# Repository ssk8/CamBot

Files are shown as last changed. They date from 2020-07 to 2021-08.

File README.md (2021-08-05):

# Auto camera tracker
in action: https://youtu.be/omu7OnxMOV8

This is an expansion on my PoC auto-tracking camera system. The first one worked but had some major shortcomings which I'm trying to address.

Steps in setup-pi are needed to get the RF24 working on the Raspberry Pi. I'm not sure if it will run as a shell script

The mount I designed to attach the HQ camera and the Pi can be found at https://www.thingiverse.com/stinkyskate/designs

The transmiter is a Feather M0 express with protowing for radio/gps attachemnt

The base station is a Pi 3A+ with HQcam and lens, proto hat with buttons, sdd1306 oled, trinket M0 (for stepper driver), radio

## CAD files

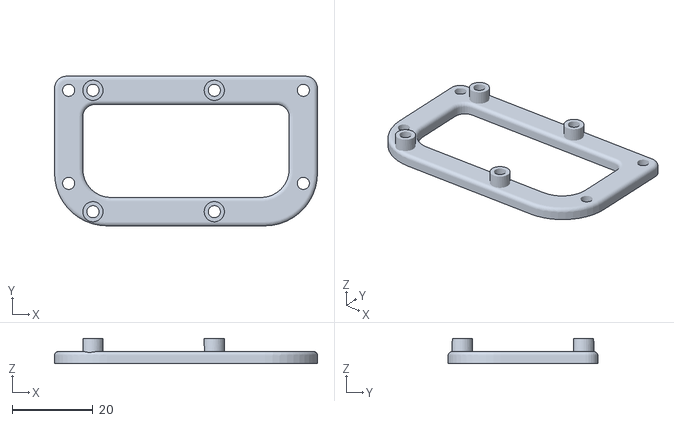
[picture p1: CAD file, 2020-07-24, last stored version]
HQZ.stl
65.0 x 37.0 x 6.25

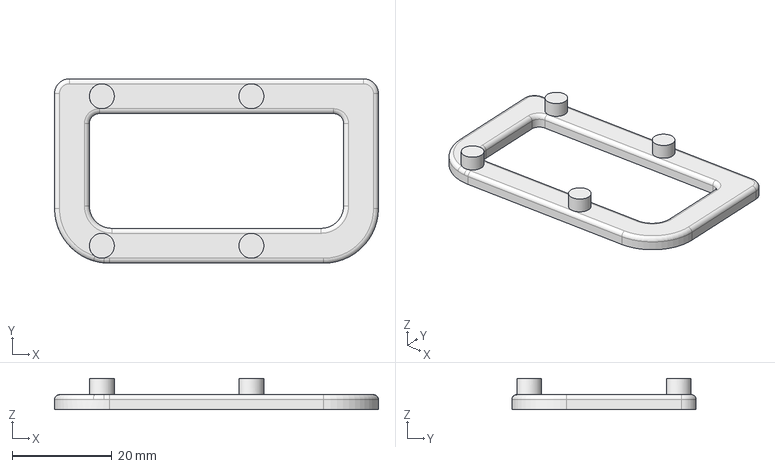
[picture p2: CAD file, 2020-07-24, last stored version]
HQZR3.FCStd
65.0 x 37.0 x 6.25 mm

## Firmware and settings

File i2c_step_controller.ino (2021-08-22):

#include <AccelStepper.h>
#include <Adafruit_DotStar.h>
#include <Wire.h>

#define nperRev 240000 
#define SLAVE_ADDRESS 0x08
#define STEPENABLEPIN 1
#define DIRPIN 3
#define STEPPIN 4
#define DATAPIN    7
#define CLOCKPIN   8 
#define DISABLE 2147483647
#define ENABLE 2147483646

AccelStepper stepper(AccelStepper::DRIVER, STEPPIN, DIRPIN);
Adafruit_DotStar strip(1, DATAPIN, CLOCKPIN, DOTSTAR_BRG);

uint32_t red = strip.Color(0, 55, 0);
uint32_t green = strip.Color(55, 0, 0);
uint32_t blue = strip.Color(0, 0, 55);


byte raw_data[3];
long rec_data = DISABLE;
long last_data;
long next_pos;
bool enabled;

void setup()
{ 
  //Serial.begin(115200);
  Wire.begin(SLAVE_ADDRESS);
  Wire.onReceive(receiveData); 
  stepper.setEnablePin(STEPENABLEPIN);
  stepper.setPinsInverted(false, false, true);
  stepper.disableOutputs ();
  enabled = false;
  stepper.setMaxSpeed(nperRev);
  stepper.setAcceleration(nperRev/20);
  stepper.setCurrentPosition(0);
  stepper.setAcceleration(2000);
  strip.begin();
  strip.setBrightness(80);
  strip.setPixelColor(0, green);
  strip.show(); 
  
}

void loop()
{
  if (last_data != rec_data) {
    if (rec_data == DISABLE) {
      stepper.disableOutputs();
      strip.setPixelColor(0, green);
      enabled = false;
    }
    else if (rec_data == ENABLE) {
      stepper.enableOutputs();
      strip.setPixelColor(0, red);
      enabled = true;
    }
    else
    { 
        next_pos = rec_data;
        if (enabled) {

          if (abs(stepper.currentPosition()-next_pos)>abs(stepper.currentPosition()-next_pos+nperRev)) next_pos-=nperRev;
          else if (abs(stepper.currentPosition()-next_pos)>abs(stepper.currentPosition()-next_pos-nperRev)) next_pos+=nperRev;
         
//          long dist = abs(stepper.currentPosition()-next_pos);
//          if (dist > 2000) stepper.setAcceleration(10000);
//          else if (dist < 200) stepper.setAcceleration(200);
//          else stepper.setAcceleration(dist*5-800);
          
          stepper.moveTo(next_pos);
      }
        else {
          stepper.setCurrentPosition(next_pos);
      }
    }
    last_data = rec_data;
  }

  
  if (enabled){
    if (stepper.isRunning()){
      strip.setPixelColor(0, blue);
    }
    else{
      strip.setPixelColor(0, red);
   }
  }

//  Serial.print("Current: ");
//  Serial.print(stepper.currentPosition());
//  Serial.print("  Target: ");
//  Serial.println(stepper.targetPosition());
  strip.show(); 
  stepper.run();
}


void receiveData(int bytecount)
{
  for (int i = 0; i < bytecount; i++) {
    raw_data[i] = Wire.read();
  }
  rec_data = 0;
  rec_data += raw_data[2] << 24;
  rec_data += raw_data[3] << 16;
  rec_data += raw_data[4] << 8;
  rec_data += raw_data[5];
}

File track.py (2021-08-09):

#!/usr/bin/python3

from time import sleep, time
from datetime import datetime, timedelta
import os, csv
from pathlib import Path
from RF24 import RF24
import struct
import picamera
import RPi.GPIO as GPIO
from orientation import distance, bearing
from subtitle import finish_subs
from stepper import send_step, step_enable
from oled import oled_print


n_per_rev = 240000

radio = RF24(17, 1)
irq_gpio_pin = 27
pipes = [0xF0F0F0F0E1, 0xF0F0F0F0D2]
struct_format = 'ffIIhhi????'
current_rx = bytearray()


class GPS_data():
    def __init__(self, latitude=0, longitude=0, gps_time="0000000", gps_date="010120", speed=0, course=0, altitude=0, button1=0, button2=0, button3=0, button4=0):
        self.latitude = latitude
        self.longitude = longitude
        self.time = datetime.strptime(f'{str(gps_date).zfill(6)[0:4]}20{str(gps_date)[-2:]}{str(gps_time).zfill(8)[:-2]}+00:00', '%d%m%Y%H%M%S%z')
        self.speed = speed
        self.course = course
        self.altitude = altitude
        self.button1 = button1


def radio_rx(channel=0):
    global current_rx
    if radio.available():
        while radio.available():
            len = radio.getDynamicPayloadSize()
            current_rx = radio.read(len)


def start_radio():
    radio.begin()
    radio.enableDynamicPayloads()
    radio.setRetries(5, 15)
#   radio.printDetails()
    GPIO.setmode(GPIO.BCM)
    GPIO.setup(irq_gpio_pin, GPIO.IN, pull_up_down=GPIO.PUD_UP)
    GPIO.add_event_detect(irq_gpio_pin, GPIO.FALLING, callback=radio_rx)
#   radio.openWritingPipe(pipes[1])
    radio.openReadingPipe(1, pipes[0])
    radio.startListening()


start_radio()


def set_camera(camera):
    camera.resolution = (1920, 1080)
    camera.framerate = 25
    camera.video_stabilization = True
    camera.annotate_foreground = picamera.Color('black')
    camera.annotate_text_size = 18
    camera.annotate_background = picamera.Color('white')


def unpack_data(struct_data):
    return struct.unpack(struct_format, struct_data)


def get_filename(data):
    path = Path("/")
    if '/mnt/usb0/Videos' in [str(x) for x in (path / 'mnt' / 'usb0').iterdir() if x.is_dir()]:
        path = path / 'mnt' / 'usb0' / 'Videos' 
    else:
        path = path / 'home' / 'pi' / 'Videos' 
    print(f'this is the path {path}')
    return f'{path}/{(data.time + timedelta(hours=-5)).strftime("%y%m%d%H%M%S")}'


def get_step_possition(base_gps, current_gps):
    pos = int(bearing(base_gps, current_gps)/360*n_per_rev)
    return pos


def move_camera(base_gps, current_gps):
    print(f"bearing: {int(bearing(base_gps, current_gps))}  distance: {distance(base_gps, current_gps)}")
    if distance(base_gps, current_gps) > 25:
        print('moving')
        send_step(get_step_possition(base_gps, current_gps))
    else:
        print("too close")


def annotate(cam, base, cur, filename):
    global v_data
    current_time = f'{(cur.time + timedelta(hours=-5)).strftime("%y/%m/%d %H:%M:%S")}'
#   cam.annotate_text = f'{current_time}\nspeed: {str(cur.speed).zfill(2)} mph\nalt: {(cur.altitude*0.0328084):.0f} ft'
    current_subtitle = f'{v_data[1]}\nSTART{time() - v_data[0]}\n{current_time} speed: {str(cur.speed).zfill(2)} mph  alt: {(cur.altitude*0.0328084):.0f} ft\n\n'
    with open(f'{filename}.srt', 'a') as subtitles:
        subtitles.write(current_subtitle)
    v_data[1] += 1


def get_target_coords_from_file() -> GPS_data:
    targets_coords_path = Path('/home/pi/target_coords.csv')
    places = dict()
    with open(targets_coords_path, newline='') as f:
        reader = csv.reader(f)
        for row in reader:
            place, lat, lon = row
            places[place] = (float(lat), float(lon))
    place = places[list(places.keys())[-1]]
    print(place)
    return GPS_data(latitude=place[0], longitude=place[1]) 


def track(button, camera):
    set_camera(camera)
    last_rx = bytearray()
    last_button1 = False
    base_gps_data = None
    current_gps_data = None
    pos_lock = False
    oled_print('start tracking')

    while True:
        if current_rx != last_rx:
            last_rx = current_rx
            current_gps_data = GPS_data(*unpack_data(current_rx))
            if not base_gps_data:
                base_gps_data = current_gps_data

            if pos_lock and current_gps_data.button1 and not last_button1:
                global v_data
                v_data = [time(), 1]
                last_button1 = current_gps_data.button1
                filename = get_filename(current_gps_data)
                camera.start_recording(f"{filename}.h264")
                print('recording')
                oled_print('recording')
            elif not current_gps_data.button1 and last_button1:
                camera.stop_recording()
                last_button1 = current_gps_data.button1
                finish_subs(filename)
                print('stopped recording')
                oled_print('stopped recording')
            #    os.system(f'ffmpeg -i {filename}.h264 -i {filename}.srt -vcodec copy -c:s mov_text {filename}.mp4')
            #    print("wrote mp4")
            #    os.system(f'rm {filename}.h264')
            if camera.recording:
                move_camera(base_gps_data, current_gps_data)
                annotate(camera, base_gps_data, current_gps_data, filename)
                
        if button.either:
            if button.both:
                break
            if button.A:
                if pos_lock:
                    print("possition lost")
                    oled_print("possition lost")
                    step_enable(False)
                    pos_lock = False
                else:
                    distant_place = get_target_coords_from_file()
                    if current_gps_data:
                        oled_print("lock possition")
                        #print(f"lock possition for {current_gps_data.latitude, current_gps_data.longitude}")
                        send_step(get_step_possition(base_gps_data, distant_place))
                        step_enable(True)
                        pos_lock = True
                    else:
                        oled_print("no current", "base possition")
                sleep(1)
            if button.B:
                if current_gps_data:
                    base_gps_data = current_gps_data
                    print("based")                    
                    oled_print("based")                    
                else:
                    print('no possition for base')
                    oled_print('no possition for base')
                sleep(1)

    step_enable(False)
    print(f'\nend tracking')
    oled_print(f'end tracking')
    sleep(1)


def main():
    from buttons import Buttons
    button = Buttons()
    camera = picamera.PiCamera()
    track(button, camera)
    camera.close()


if __name__ == "__main__":
    try:
        main()
    except KeyboardInterrupt:
        print(f"\ndone")
    finally:
        GPIO.cleanup() 

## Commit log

2020-07-12 Update gps_rx2.py
    pin changes, refactor
2020-07-15 Update gps_rx2.py
    pin changes
2020-07-15 pin changes, now on M0 (SAMD)
2020-07-16 added button
2020-07-24 3d models for attaching pi zero to HQ camera
    [HQZ.stl, HQZR3.FCStd]
2020-08-06 new display driver
2020-09-11 added color LED for gps/recording indicator
2020-10-03 added 3:1 gear updates
2021-06-01 move to geared stepper
    changed step to long, updated other constants
2021-06-01 geared stepper test
2021-07-01 finish button mod
2021-07-21 track integration to ui
2021-07-21 add button timer
2021-07-30 path stuff
    [HQZ.stl, HQZR3.FCStd]
2021-08-04 add timelapse and fix buttons
    [buttons.py, oled.py, time_lapse.py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]
